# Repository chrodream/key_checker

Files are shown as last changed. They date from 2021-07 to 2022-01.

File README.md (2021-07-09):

# Key Checker

## Overview

	・Know the lock status of each room by HTTP communication between the primary device(Raspberry Pi) and the secondary device(ESP32).
	・See in the log when the door was locked or unlocked.

## Environment

	・Raspberry Pi
	・ESP32 Devkit-C 32D/E

## Parts list

### Primary (Raspberry Pi)

| Products | Quantity |
| --- | --- |
| Raspberry Pi | 1 |
| micro SD Card(Limit to 32GB if you use 32bit OS) | 1 |

### Secondary (ESP32)

| Products | KiCAD assign | Quantity (per each) |
| --- | --- | --- |
| [ESP32-DevkitC-32](https://akizukidenshi.com/catalog/g/gM-15673/) | U1 | 1 |
| [0.96inch OLED](https://akizukidenshi.com/catalog/g/gP-12031/) | U2 | 1 |
| 3mm Power LED (No specification) | D1 | 1 |
| [5mm RGB LED](https://www.marutsu.co.jp/pc/i/1356696/) | D2 | 1 |
| [30kΩ Semi-fixed resistance](https://akizukidenshi.com/catalog/g/gP-14907/) | RV1 | 1 |
| 470Ω Chip-resistor | R1, R2, R3, R4 | 4 |
| 10kΩ Chip-resistor | R5, R6, R7 | 3 |
| [Micro switch](https://akizukidenshi.com/catalog/g/gP-14659/) | SW1 | 1 |
| [Illumination sensor ](https://akizukidenshi.com/catalog/g/gI-02325/) | Q1 | 1 |
| 3-Pin socket | J1, J2 | 2 |
| 3-line wire | | 1 |

## Usage

1. Launch key_server.py on Raspberry Pi 
   e.g. `python3 ~/key_checker/key_server.py`
2. upload client_esp.ino to ESP32.
   **Notice: Please change Wi-Fi's SSID, Password and Room number.**
3. Sends a HTTP data per 10 seconds when ESP is connected to Power supply.

## Trouble-shooting

| Error Code | Response method |
| --- | --- |
| -1 | Maybe Network configuration is wrong. Please check IP-address, Subnet mask, DNS and Home Gate Way's address are correct. |
| -11 | Please do not launch on SSH. |
| 3-digits number | It's HTTP response code. |

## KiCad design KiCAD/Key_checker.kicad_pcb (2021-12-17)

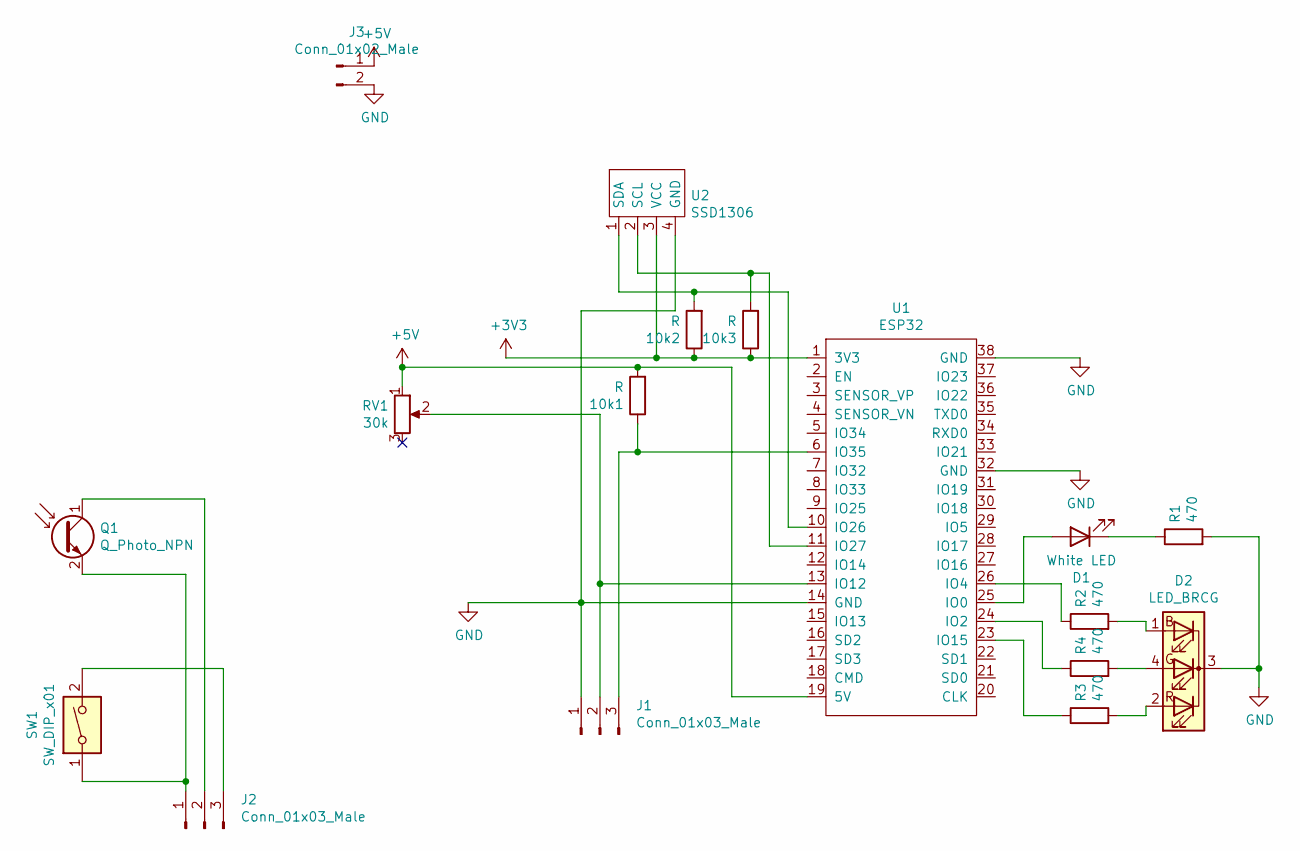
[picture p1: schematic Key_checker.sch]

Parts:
10k1, 10k2, 10k3: R; R_0603_1608Metric_Pad0.98x0.95mm_HandSolder
D1: White LED; LED_D3.0mm
D2: LED_BRCG; LED_D5.0mm-4_RGB
J1, J2: Conn_01x03_Male; PinHeader_1x03_P2.54mm_Horizontal
J3: Conn_01x02_Male; PinHeader_1x02_P2.54mm_Horizontal
Q1: Q_Photo_NPN; LED_D5.0mm
R1, R2, R3, R4: 470; R_0603_1608Metric_Pad0.98x0.95mm_HandSolder
RV1: 30k; Potentiometer_ACP_CA6-H2,5_Horizontal
SW1: SW_DIP_x01; SS-10GL
U1: ESP32; DIP-38_1000_ELL
U2: SSD1306; PinHeader_1x04_P2.54mm_Vertical

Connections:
+3V3: 10k2.1, 10k3.1, U1.1 (3V3), U2.3 (VCC)
+5V: 10k1.2, J3.1, RV1.1, U1.19 (5V)
GND: D2.3 (K), J1.1, J3.2, R1.2, U1.14 (GND), U1.32 (GND), U1.38 (GND), U2.4 (GND)
unnamed: 10k1.1, J1.3, U1.6 (IO35)
unnamed: 10k2.2, U1.10 (IO26), U2.1 (SDA)
unnamed: 10k3.2, U1.11 (IO27), U2.2 (SCL)
unnamed: D1.1 (K), R1.1
unnamed: D1.2 (A), U1.25 (IO0)
unnamed: D2.1 (BA), R2.2
unnamed: D2.2 (RA), R3.2
unnamed: D2.4 (GA), R4.2
unnamed: J1.2, RV1.2, U1.13 (IO12)
unnamed: J2.1, Q1.2 (E), SW1.1
unnamed: J2.2, Q1.1 (C)
unnamed: J2.3, SW1.2
unnamed: R2.1, U1.26 (IO4)
unnamed: R3.1, U1.23 (IO15)
unnamed: R4.1, U1.24 (IO2)

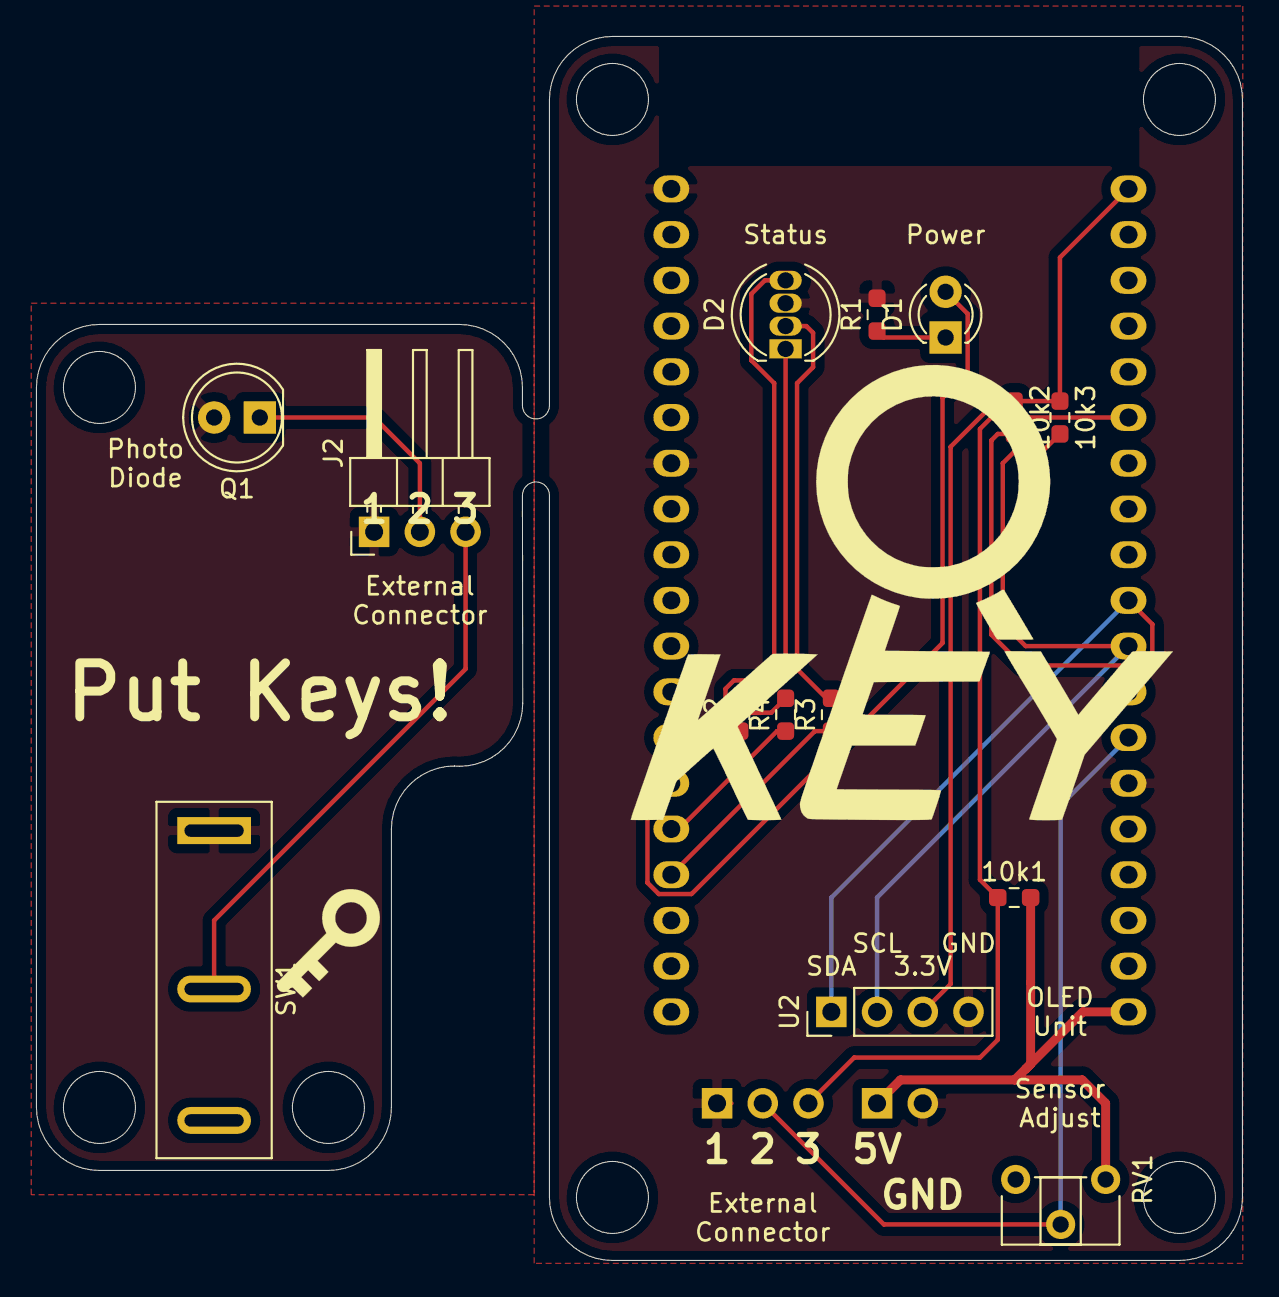
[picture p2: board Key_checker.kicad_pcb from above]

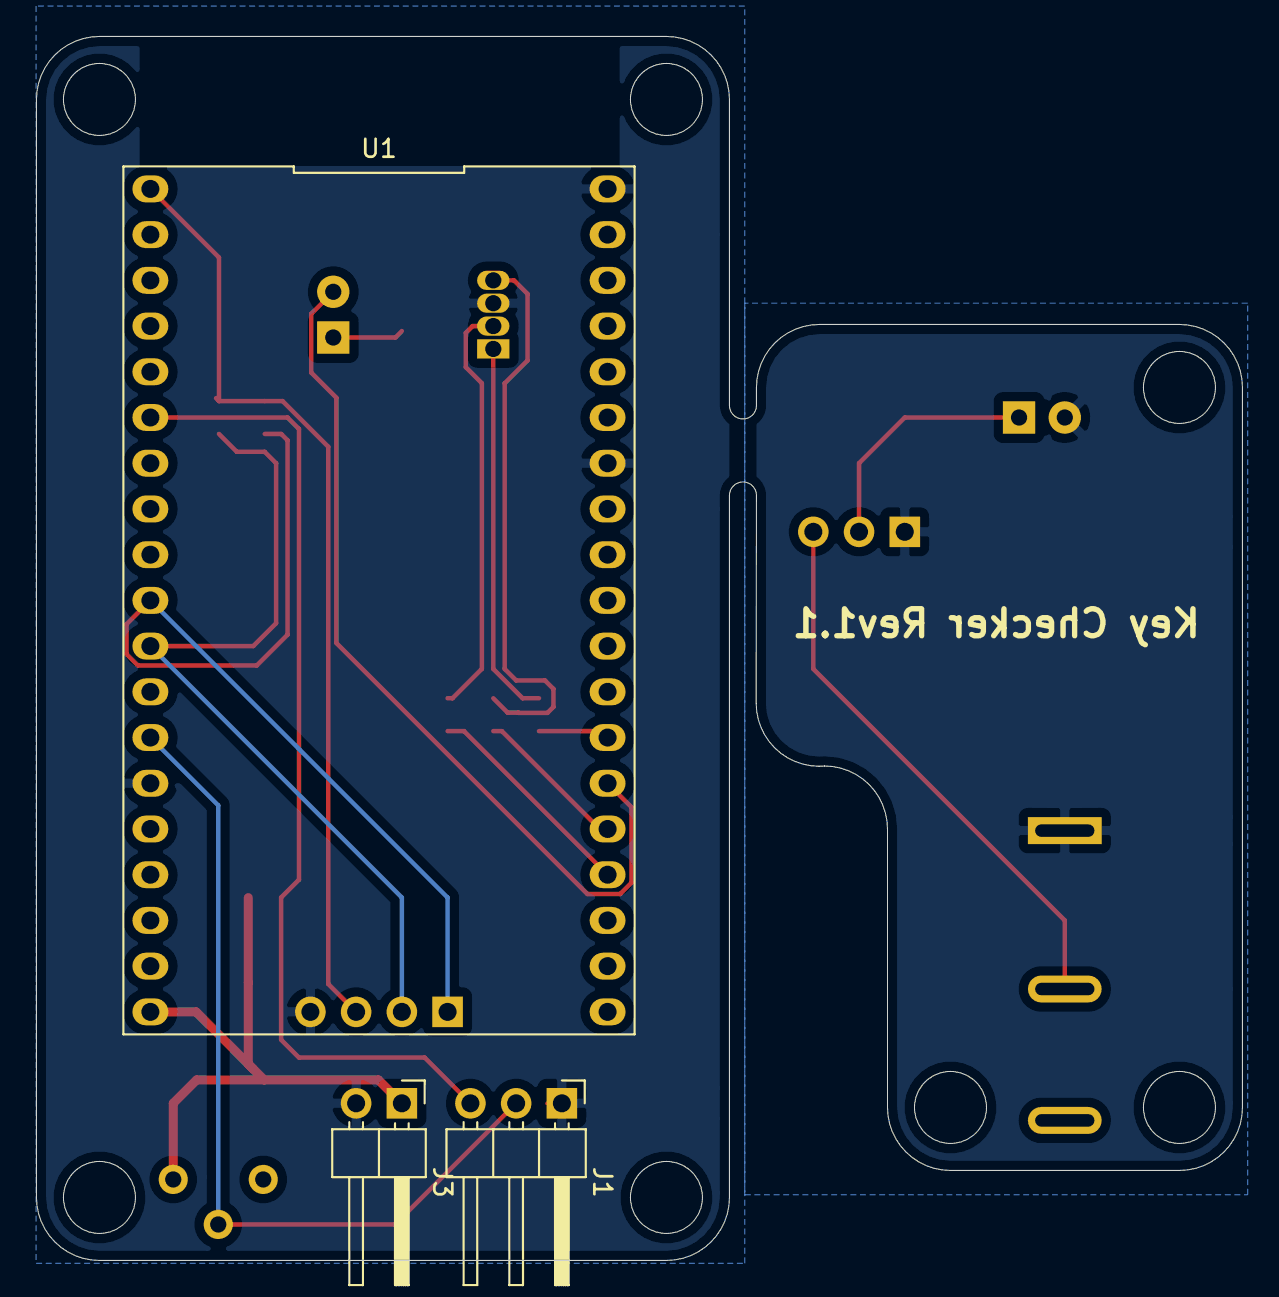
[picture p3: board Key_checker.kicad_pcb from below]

Board: 2 copper layers, 67.0 x 68.0 mm, 17 parts (3 on the bottom side), 18 nets.

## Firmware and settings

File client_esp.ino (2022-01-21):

#include <WiFi.h>
#include <HTTPClient.h>
#include <iostream>
#include <cstring>
#include <sstream>
#include <Wire.h>
#include "SSD1306.h"

// Configuration
const char ssid[] = "SSID";  // SSID
const char pass[] = "Pass"; // Password
const char serverName[] = "http://192.168.0.100:2001/";
static const int room_number = 205;

unsigned long lastTime = 0;
unsigned long timerDelay = 0;
const IPAddress ip_client(192, 168, 0, room_number); // Your IP address
const IPAddress gateway(192, 168, 0, 1);
const IPAddress dns(192, 168, 0, 1);
const IPAddress subnet(255, 255, 255, 0);
static WiFiClient client;

const int key_switch = 35;
const int photo_tr = 12;

const int red_led = 2;    // WiFi cannot connect
const int yellow_led = 4; // Posting error
const int white_led = 0;  // Power LED
const int blue_led = 15;  // Posting data successfully

const int RED = 1;
const int YELLOW = 2;
const int led_level_bit = 8;
const int led_freq = 1000;

SSD1306 display(0x3c, 26, 27);

void error(int code); // When ESP occurred errors

void setup()
{
  // Setting input pin
  pinMode(key_switch, INPUT);
  pinMode(photo_tr, INPUT);
  pinMode(red_led, OUTPUT);
  pinMode(yellow_led, OUTPUT);
  pinMode(white_led, OUTPUT);
  digitalWrite(white_led, HIGH);
  digitalWrite(blue_led, LOW);
  ledcSetup(RED, led_freq, led_level_bit);
  ledcSetup(YELLOW, led_freq, led_level_bit);
  ledcAttachPin(red_led, RED);
  ledcAttachPin(yellow_led, YELLOW);

  // Starting Wi-Fi
  Serial.begin(115200);
  WiFi.config(ip_client, gateway, subnet, dns); // Set static IP
  WiFi.begin(ssid, pass);                       // Connect to server
  Serial.print("Connecting");
  int count = 0;
  while (WiFi.status() != WL_CONNECTED)
  {
    Serial.print(".");
    delay(500);
    count++;
    if (count >= 20) // if ESP cannot connect for 10 sec.
    {
      error(1);
    }
  }
  Serial.print("\n");
  Serial.println("WiFi Connected");
  Serial.print("IP Address: ");
  Serial.println(WiFi.localIP());

  display.init();
  display.setFont(ArialMT_Plain_10);
  display.drawString(0, 0, "Connected");
  display.drawString(0, 10, WiFi.localIP().toString());
  display.setFont(ArialMT_Plain_24);
  display.drawString(0, 20, "Room");
  display.drawString(70, 20, (String)room_number);
  display.display();
}

void loop()
{
  int check_sum = room_number * 7;
  std::string key_stat;
  std::string light_stat;

  // Check Key status and Light status
  for (int loop_count = 0; loop_count < 100; loop_count++)
  {
    display.clear();
    display.setFont(ArialMT_Plain_16);
    if (digitalRead(key_switch) == HIGH && digitalRead(photo_tr) == LOW)
    {
      key_stat = "0";
      light_stat = "1";
      display.drawString(0, 45, "Key");
      display.drawString(64, 45, "Light");
    }
    else if (digitalRead(key_switch) == HIGH && digitalRead(photo_tr) == HIGH)
    {
      key_stat = "0";
      light_stat = "0";
      display.drawString(0, 45, "Key");
    }
    else if (digitalRead(key_switch) == LOW && digitalRead(photo_tr) == LOW)
    {
      key_stat = "1";
      light_stat = "1";
      display.drawString(64, 45, "Light");
    }
    else
    {
      key_stat = "1";
      light_stat = "0";
    }

    display.setFont(ArialMT_Plain_10);
    display.drawString(0, 0, "Connected");
    display.drawString(0, 10, WiFi.localIP().toString());
    display.setFont(ArialMT_Plain_24);
    display.drawString(0, 20, "Room");
    display.drawString(70, 20, (String)room_number);
    display.display();
    delay(100);
  }
  // check status for checksum
  if (key_stat == "1")
  {
    check_sum += 5;
  }
  if (light_stat == "1")
  {
    check_sum += 3;
  }
  // check_sum %= 100;

  // make send text
  std::ostringstream room_number_ostring;
  std::ostringstream check_digit_ostring;
  room_number_ostring << room_number;
  check_digit_ostring << check_sum;
  std::string send_std_string = "room_num=";
  send_std_string.append(room_number_ostring.str());
  send_std_string.append("&key_stat=");
  send_std_string.append(key_stat);
  send_std_string.append("&light_stat=");
  send_std_string.append(light_stat);
  send_std_string.append("&check_sum=");
  send_std_string.append(check_digit_ostring.str());

  // convert from std::string to char arry
  int send_std_string_count = send_std_string.length();
  char sendtext[send_std_string_count + 1];
  strcpy(sendtext, send_std_string.c_str());
  Serial.println(sendtext);

  // Send data to Server over Wi-Fi
  if (WiFi.status() == WL_CONNECTED) // Check WiFi connection status
  {
    HTTPClient http;

    http.begin(serverName);                                              // Specify destination for HTTP request
    http.addHeader("Content-Type", "application/x-www-form-urlencoded"); // Specify content-type header

    int httpResponseCode = http.POST(sendtext); // Send the actual POST request

    if (httpResponseCode > 0)
    {
      String response = http.getString(); // Get the response to the request
      Serial.println(httpResponseCode);   // Print return code
      Serial.println(response);           // Print request answer
      if (httpResponseCode >= 100 && httpResponseCode <= 299)
      {
        digitalWrite(blue_led, HIGH);
        delay(200);
        digitalWrite(blue_led, LOW);
      }
      else
      {
        error(httpResponseCode);
      }
    }
    else
    {
      Serial.print("Error on sending POST: ");
      Serial.println(httpResponseCode);
      error(httpResponseCode);
    }
    http.end(); // Free resources
  }
  else
  {
    Serial.println("Error in WiFi connection");
    error(1);
  }
}

void error(int code)
{
  digitalWrite(white_led, LOW);
  display.clear();
  display.setFont(ArialMT_Plain_16);
  int rep, lap = 0;
  if (code >= 100)
  {
    rep = code;
    code = 2;
  }
  int level = 0;
  while (1)
  {
    lap++;
    while (1)
    {
      if (level > 250)
      {
        level = 250;
        break;
      }
      ledcWrite(code, level);
      level++;
      display.drawString(0, 0, "Error code");
      display.drawString(80, 0, (String)code);
      if (code == 1)
      {
        display.drawString(0, 20, "No Wi-Fi");
        display.drawString(0, 40, "connection");
      }
      else if (code == 2)
      {
        display.drawString(0, 20, "Reqest Error");
        display.drawString(0, 40, "Code: ");
        display.drawString(50, 40, (String)rep);
      }
      else if (code == -1)
      {
        display.drawString(0, 20, "No Reply");
        display.drawString(0, 40, "from server");
      }
      else
      {
        display.drawString(0, 20, "Unknown Error");
      }
      display.display();
      delay(3);
    }

    display.clear();
    while (1)
    {
      if (level < 0)
      {
        level = 0;
        break;
      }
      ledcWrite(code, level);
      level--;
      display.drawString(0, 0, "Error code");
      display.drawString(80, 0, (String)code);
      display.display();
      delay(3);
    }
    display.clear();

    if (lap >= 5)
    {
      display.setFont(ArialMT_Plain_16);
      display.drawString(0, 0, "Retrying");
      display.display();
      for (int i = 60; i <= 90; i = i + 5)
      {
        display.drawString(i, 0, ".");
        display.display();
        delay(500);
      }
      ESP.restart(); // Reboot ESP32
    }
  }
}

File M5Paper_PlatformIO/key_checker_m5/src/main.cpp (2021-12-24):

#include <M5EPD.h>
#include <WiFi.h>

M5EPD_Canvas canvas(&M5.EPD);
// uint32_t getPercent(void);

void setup()
{
    // M5 startup
    M5.begin();
    M5.BatteryADCBegin();
    M5.EPD.SetRotation(90);
    M5.EPD.Clear(true);
    WiFi.begin("Sguest-2g", "Senkou107");

    while (WiFi.status() != WL_CONNECTED)
    {
        delay(500);
        Serial.print(".");
    }
    Serial.print("Connected!");
    canvas.createCanvas(540, 960);
    canvas.setTextSize(3);
    canvas.drawJpgUrl("https://shinycolors.idolmaster.jp/pc/static/img/download/wallpaper/wp_hokagoclimaxgirls_750x1334.jpg");
    // canvas.drawJpgFile(SD, "/img.jpg"); // read image in SD card
    canvas.pushCanvas(0, 0, UPDATE_MODE_GC16);
    delay(3000);

    // サーバの設定
}

void loop()
{
    // サーバーにデータの要求
    // データを格納
    // EPDで表示
    canvas.drawString("Hello World", 185, 48);
    canvas.drawNumber(M5.getBatteryVoltage(), 200, 100);
    delay(300 * 1000); // wait 5 minutes
}

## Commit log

2021-05-28 Changed to HTTP server style
    [Roomlist.csv]
2021-06-01 Added writing from key_server.py data to roomlog.csv
    [roomlog.csv]
2021-06-11 fix server and ESP's Wi-Fi bug, added key and light Sensor
    [roomlog.csv]
2021-06-22 Added GUI mode
    [roomlog.csv]
2021-06-25 added OLED mode, fix some bug
    [client_esp.ino]
2021-06-25 Add PCB data
    [Key_checker.kicad_pcb, Key_checker.sch]
2021-07-02 fix some bugs
    [roomlog.csv]
2021-07-02 nothing spectial
    [Roomlist.csv, roomlog.csv]
2021-07-02 Key Checker's PCB is Completed!
    [Key_checker-B_Cu.gbl, Key_checker-B_Mask.gbs, Key_checker-B_Paste.gbp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]
2021-07-09 Fixed problem in PCB
    [Key_checker.sch]
2021-07-16 fixed PCB
    [Key_checker-B_Cu.gbl, Key_checker-B_Mask.gbs, Key_checker-B_Paste.gbp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]
2021-12-03 PCB is changed
    [Key_checker-B_Cu.gbl, Key_checker-B_Mask.gbs, Key_checker-B_Paste.gbp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]
2021-12-14 Prepare for M5Paper
    [Key_checker-B_Cu.gbl, Key_checker-B_Mask.gbs, Key_checker-B_Paste.gbp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]
2021-12-17 Modified PCB
    [Key_checker-B_Cu.gbl, Key_checker-B_Mask.gbs, Key_checker-B_Paste.gbp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]
2022-01-13 add checksum function
    [roomlog.csv, roomlog_2022_1_13.csv]
2022-01-20 add checksum for ESP32
    [roomlog_2022_1_20.csv]
2022-01-21 fix bug in client_esp.ino and add gui.html
    [roomlog_2022_1_13.csv, roomlog_2022_1_20.csv]
